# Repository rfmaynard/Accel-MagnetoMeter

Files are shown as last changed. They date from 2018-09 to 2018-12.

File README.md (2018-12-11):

Accel/Magnetometer project build instructions
=============================================

Table of Contents
-----------------

1.  [Introduction](https://github.com/rfmaynard/Accel-MagnetoMeter#introduction)

2.  [Bill of
    Materials/Budget](https://github.com/rfmaynard/Accel-MagnetoMeter#bill-of-materialsbudget)

3.  [Time](https://github.com/rfmaynard/Accel-MagnetoMeter#time)

4.  [Assembly](https://github.com/rfmaynard/Accel-MagnetoMeter#assembly)

5.  [PCB/Soldering](https://github.com/rfmaynard/Accel-MagnetoMeter#pcbsoldering)

6.  [Power Up](https://github.com/rfmaynard/Accel-MagnetoMeter#power-up)

7.  [Unit Testing](https://github.com/rfmaynard/Accel-MagnetoMeter#unit-testing)

8.  [Production
    Testing](/github.com/rfmaynard/Accel-MagnetoMeter#production-testing)

### Introduction

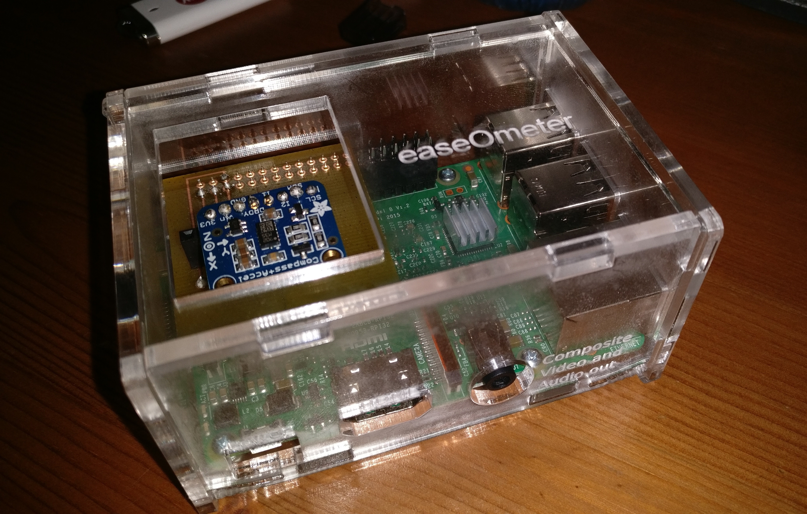
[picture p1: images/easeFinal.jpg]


Hello and welcome to the (unofficial) build instructions and guide to using the
LSM303 Accelerometer and Magnetometer. The scope of this little project is to
learn and integrate a piece of hardware and broadcomm development platform
together. In our case, we will be using a Raspberry Pi B as our platform. All of
which can then be used for real world applications. A potential case for this
project, imaged below, which my group and I will be attempting in the next
semester, will be a simple pedometer.

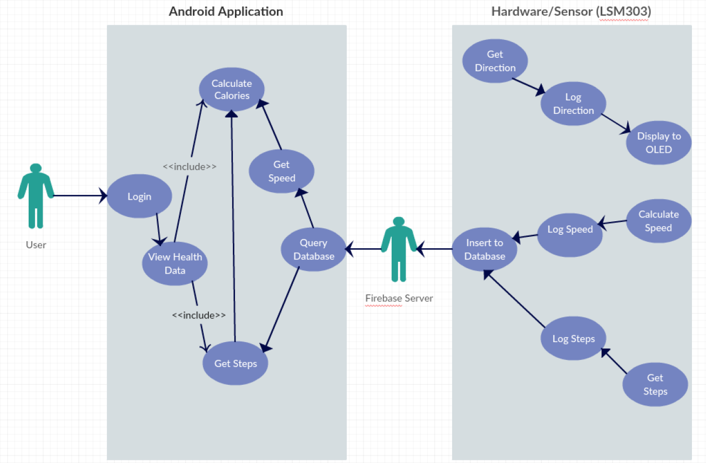
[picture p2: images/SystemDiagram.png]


Now let’s get into it!

### Bill of Materials/Budget

Budget with part links
[HERE](https://github.com/rfmaynard/Accel-MagnetoMeter/blob/master/documentation/BeginnerBudget.xlsx)

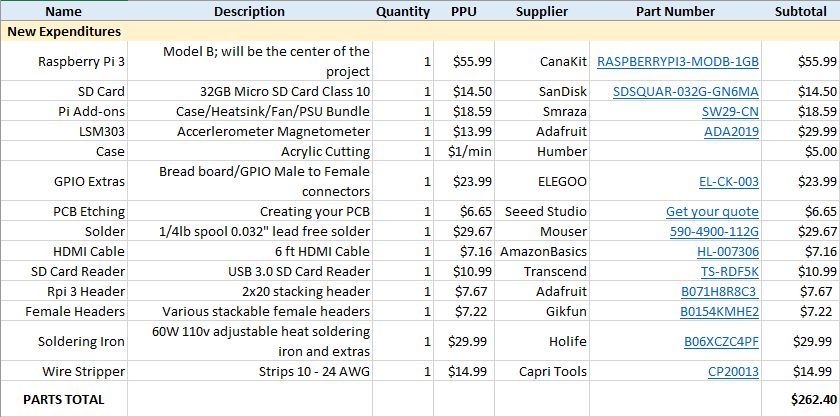
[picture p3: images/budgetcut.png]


Firstly, you will need to acquire certain parts in order to complete this
project. Shown above is the price break down for each component used. You may
not need all of them listed items, but it is everything I was required to use to
get the project to completion. Feel free to download the spreadsheet version of
the budget, as part links are provided.

### Time

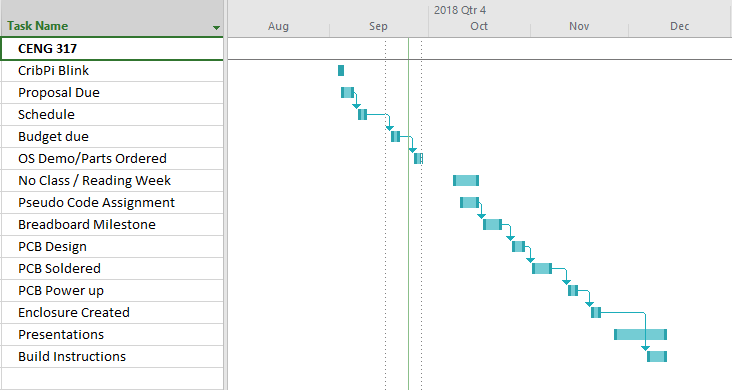
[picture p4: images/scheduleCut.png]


This project ran its course over an entire school semester (4 months, \~15
weeks), and the amount of time spent on it per week, on average, I’d say was
about 1 to 2 hours. Assuming that those reading this are at the average skill
level in using a computer and hardware, a user would be able to complete this
potentially over a weekend. The one time constraint that isn’t always certain is
how long the parts will take to arrive. When ordering your parts, ensure that
the seller/supplier provides appropriate delivery time estimates. This will
ensure smooth assembly of your project!

### Assembly

**Step 1: Preparing your Raspberry Pi**

In this step we will cover basic Raspberry Pi imaging so you are able to login
and access your device to test and drive your sensor later on!

1.  Download the latest [Raspberry Pi
    image](https://www.raspberrypi.org/downloads/). My recommendation is NOOBS.
    This will ensure that starting off, you will have almost everything you need
    if you decide to re-purpose the device later on.

2.  Download [etcher](https://www.balena.io/etcher/). This program will allow
    you to burn the Raspberry Pi image to your SD card.

3.  Insert your SD card into the SD card reader and plug it into your computer.

4.  Open etcher and follow the on screen instructions to burn your image. I
    found this program the easiest to use. [Extra documentation if
    needed](https://www.raspberrypi.org/documentation/installation/installing-images/README.md).

5.  Insert the SD card into your Raspberry Pi along the underside of the device,
    logo facing out. Plug all of the required cables in such as: Ethernet, HDMI
    cable, mouse, keyboard, power, and turn the device on.

6.  Upon boot you will see an option for different operating systems. Select
    **Raspbian** and follow the on screen instructions to complete the OS
    install. If you want, grab a coffee or snack as the install may take some
    time.

7.  At this point the Pi should boot to desktop. Follow the additional set up
    options on screen.

8.  Enable I2C. This is the method we will be using to communicated with our
    Raspberry Pi. Type `sudo apt-get install -y python-smbus i2c-tools` into the
    terminal by pressing `ctrl+alt+t`.

9.  Type `sudo raspi-config` into the terminal.

10. Go to interfacing options \> and enable I2C.

11. Power down with `sudo powerdown` from the terminal by pressing and set the
    Pi aside. We will not be using it until sensor testing.

**Step 2: Breadboarding and prototyping**

Here I will cover basic sensor connectivity to the Raspberry Pi by using a
breadboard for creating a mock layout/design that will be used in the PCB
creation stage.

1.  Gather the following items: Breadboard, LSM303 Sensor, and 4 Female-to-Male
    GPIO cables.

2.  Identify the labels on the sensor. For basic usage, we will be using: 3.3v,
    GND, SDA, and SCL.

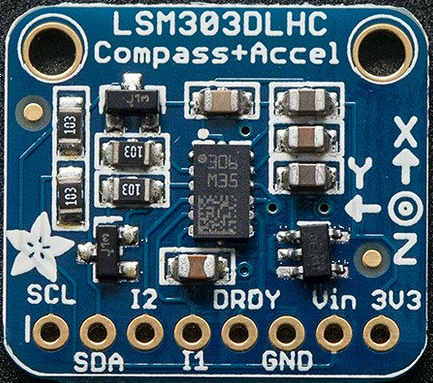
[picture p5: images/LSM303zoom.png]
    

3.  Identify the corresponding pinouts on the Raspberry Pi. [This website is a
    great tool to use if your are unsure.](https://pinout.xyz/#)

4.  Plug in the female part of the GPIO cables into the Raspberry Pi’s 1,3,5,
    and 6 pins, based on the chart from pinout.xyz. These are the pins we are
    going to be using for this project.

5.  Using the 8-pin connector that came with the LSM303 sensor, plug it into the
    breadboard and rest the LSM303 onto it as a placeholder.

6.  Connect the corresponding cables from the Raspberry Pi into the matched
    holes for the sensor.

7.  Voila! You have your mock up sensor connection!

It should look something like this:

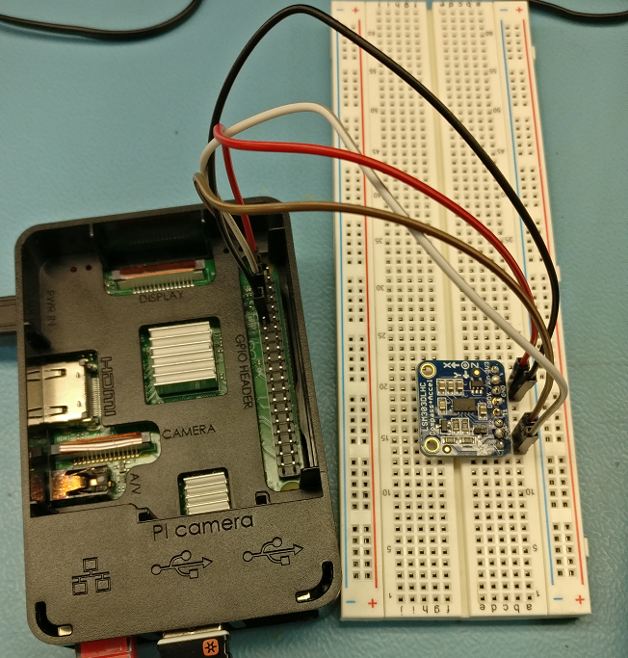
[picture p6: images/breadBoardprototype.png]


Now we can proceed to the PCB and soldering!

### PCB/Soldering

This is the part of the project that needs to be proceeded with care and
caution. I have made mistakes with my PCB design and case, however, I am
fortunate enough to have the resources at Humber to create 2nd or 3rd revisions
within a day or two. For those without access to such resources, it is advised
to double check your designs before purchasing etching and cutting services.

**Step 1: Fritzing**

[Fritzing](http://fritzing.org/download/) is an open-source application that
easily allows the user to create PCB schematics for different development
platforms. It is highly customizable and easy to use.

1.  [Download](http://fritzing.org/download/) and extract Fritzing. Installation
    notes are on the linked page for various operating systems.

2.  (Optional) Download the [AdaFruit Fritzing
    Library.](https://github.com/adafruit/Fritzing-Library) Handy if you want to
    take the extra step and create a mock or your own connection/designs in
    Fritzing.

3.  Download my Fritzing file
    [here](https://github.com/rfmaynard/Accel-MagnetoMeter/blob/master/pcb%20files/LSM303pi2.fzz)
    and open it. From the PCB tab, you can make changes at your leisure and pick
    it apart to see how it was made.

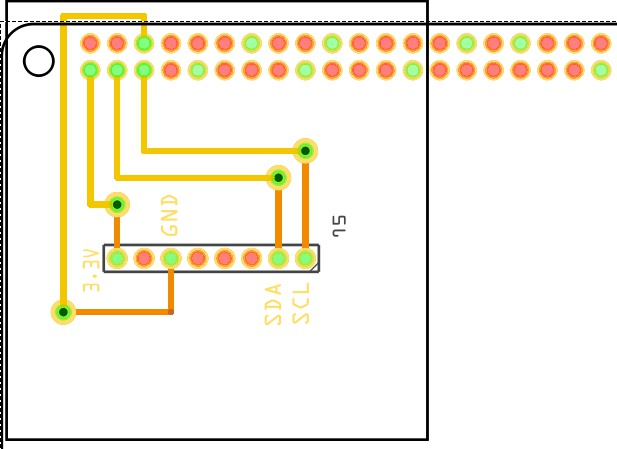
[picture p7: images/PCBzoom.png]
    

4.  Export as gerber. `File > Export for Production > Extended Gerber` and
    select an appropriate folder. These files will be required to create and
    etch your PCB.

5.  Zip/Compress the folder containing your gerber files and send them to your
    etcher of choice.

**Step 2: Soldering**

Once you have your PCB we are ready to solder our parts. **Note:** if you made
your own Fritzing design, please double check that it has the correct
connections.

1.  Gather your LSM303 sensor, copper wire, wire stripper, the 8-pin that came
    with the sensor, your PCB, solder, and soldering iron.

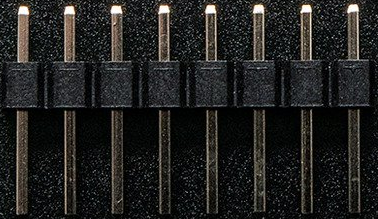
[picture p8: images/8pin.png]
    

2.  Solder your 8-pin that came with your sensor, pictured above, to your
    LSM303. Put the longer end of the 8-pin into your breadboard and place your
    sensor holes into the upright pins and solder all of the pins. This will
    ensure your sensor doesn’t move too much during soldering and a sturdy
    connection. **Note:** [Watch this video on soldering
    tips.](https://www.youtube.com/watch?v=oqV2xU1fee8) **Solder in a well
    ventilated area and use safety glasses.**

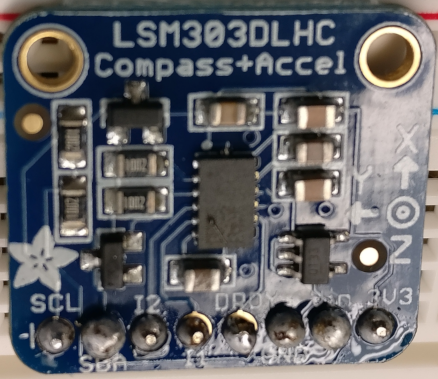
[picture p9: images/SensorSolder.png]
    

3.  (Optional) At this point you can test your sensor by applying it to the
    breadboard mockup from the previous section. Turn on your Pi with the sensor
    connected and run `i2cdetect -y 1` in the terminal. If working, should
    display the addresses `19` and `1e`.

4.  Solder your vias on your PCB. The easiest method I found, was to strip your
    copper wiring, stick it into the breadboard, and slide one via onto it so
    that it is flat and stable for soldering. Imaged below, and repeat for each
    via. Once each via is soldered, snip the excess wire with your cutters.

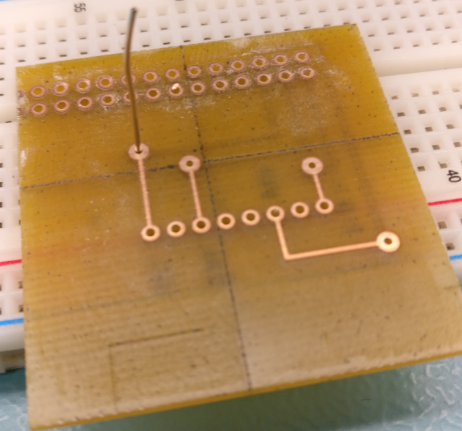
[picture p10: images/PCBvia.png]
    

5.  Solder your stackable headers. Using the breadboard again, take some extra
    copper wire from the snipped vias, or strip more, and place it into the
    female part of the header. The more, the sturdier. Flip the header over and
    plug it into the breadboard. Place your PCB onto the pins sticking out and
    solder the connections. Example below.

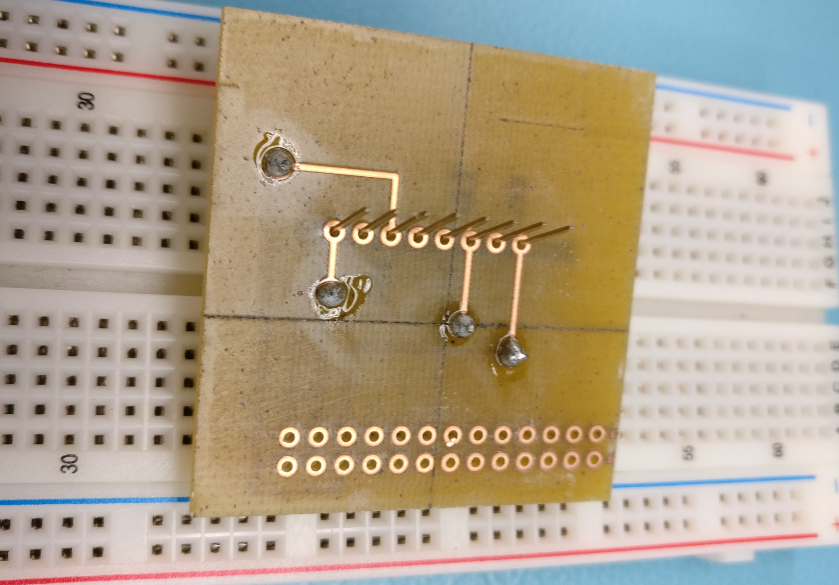
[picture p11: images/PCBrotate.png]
    

6.  Repeat the process for the 2x20 header for the Raspberry Pi. It’s not
    entirely necessary to solder all of the vias, but it ensures the PCB does
    not move as much.

7.  Your soldering should be complete. Plug everything in accordingly (i.e line
    up sensor to the correct vias and Pi header is soldered on 1,3,5 and 6), and
    you should be ready for the next step! Example below.

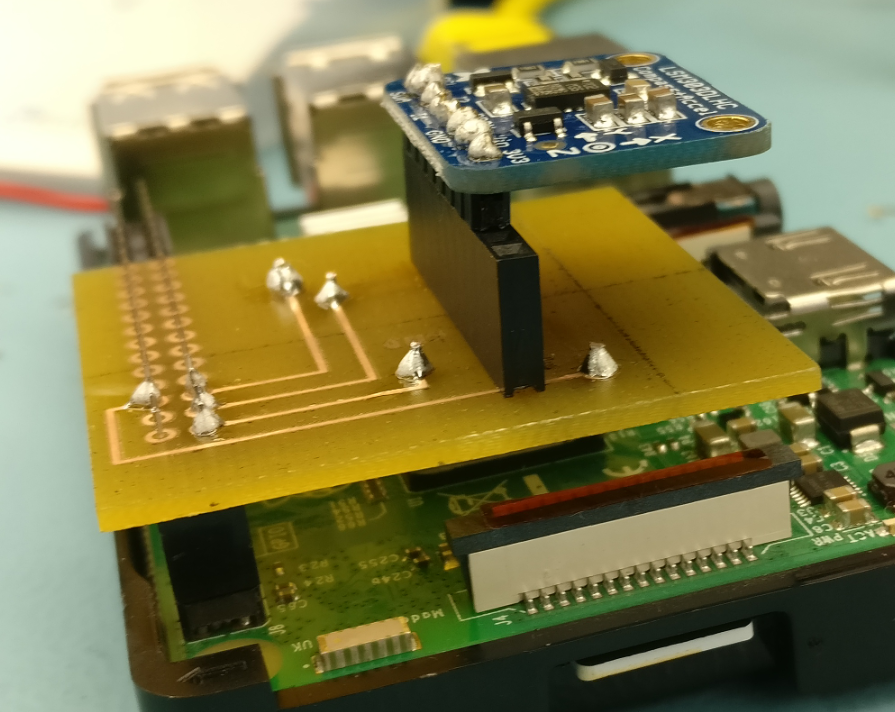
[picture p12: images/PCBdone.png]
    

### Power Up

Once everything is plugged in, and you have double checked your connections,
power on your Raspberry Pi.

1.  Open up the terminal once you are at the desktop, and run the command
    `i2cdetect -y 1`.

2.  Hopefully everything is in working order. If so, you will see this screen:

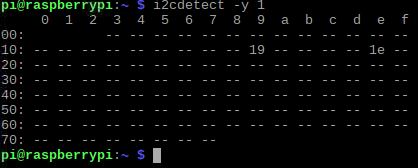
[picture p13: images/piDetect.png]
    

Congratulations! You can now move onto Unit Testing.

### Unit Testing

For this portion, you will need an internet connection as you will be required
to download libraries in order to get readings from the LSM303 sensor.

1.  Make sure your Pi is up to date with the latest packages. Run `sudo apt
    update` in the terminal to make sure everything is up to date.

2.  We will be using Python to test the LSM303 sensor, and will need the
    appropriate tools. Run the following commands in the terminal to ensure we
    have everything required to read from the sensor.

~~~~~~~~~~~~~~~~~~~~~~~~~~~~~~~~~~~~~~~~~~~~~~~~~~~~~~~~~~~~~~~~~~~~~~~~~~~~~~~~
sudo apt-get install git build-essential python-dev
cd ~
git clone https://github.com/adafruit/Adafruit_Python_LSM303.git
cd Adafruit_Python_LSM303
sudo python setup.py install
~~~~~~~~~~~~~~~~~~~~~~~~~~~~~~~~~~~~~~~~~~~~~~~~~~~~~~~~~~~~~~~~~~~~~~~~~~~~~~~~

3.  Navigate to the `/Adafruit_Python_LSM303/examples` directory.

4.  Test your sensor by running `python simpletest.py`. Your readings should
    look like this:

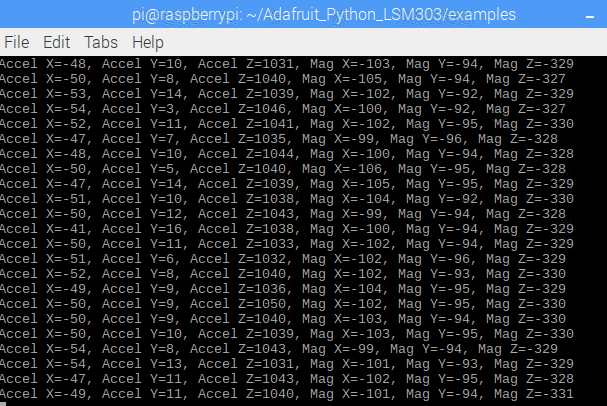
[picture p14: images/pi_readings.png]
    

5.  You can test the readings by moving your device in different directions with
    different speeds. You will notice the values changing accordingly.

Congratulations! Your sensor successfully works with your etched PCB and
Raspberry Pi. You can move onto Production Testing.

### Production Testing

[I have provided a case
file](https://github.com/rfmaynard/Accel-MagnetoMeter/blob/master/case%20files/easeOmeter_CaseFiles_v4.cdr)
(Created with CorelDraw x6) for those that wish to continue further for
potential real world use. This case will ensure your sensor, Pi, and PCB are
protected all while providing enough room for you to remove the sensor at your
leisure. For portability, there is definite room that can be improved upon if
you wish to make the device smaller and more portable. For my purposes, this
project was meant to be a robust and simple type pedometer prototype for the
aging population. I have taken it to and from school inside of my backpack for a
solid hour at a time and everything still works with no issues. This concludes
the end of the build instructions, I hope you had fun with this project as much
as I did!

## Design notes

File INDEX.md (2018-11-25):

easeOmeter project
==================

November 20th, 2018
-------------------

### Enclosure update:

Working with CorelDraw x6, we were provided a default file to work with. My
current edited version is just tall enough for the user to reach down and remove
the sensor, while still providing protection during transport.



As I write this, the prototype lab is in the process of cutting the acrylic
case. Below is the result of the case. However, it is apparent that the case is
still slightly flawed. I will need to make the top square for removing and
adding sensors slightly larger, and the PCB is just marginally too large. In
addition, I will need to procure standoffs for the Pi so it can stay elevated
inside the case. I was thinking of making those out of the acrylic from the
cuts. I will post an edited and updated case file as I continue to make
measurements and work on it.



Currently, the project remains on track and I double checked the sensor and Pi’s
functionality and everything is in working order. Financial status is unchanged
as I was able to acquire a custom case through the school thanks to the
prototype lab.

### Adjustments:



The above image details the above changes I mentioned. The indent in the side
panel will ensure my PCB will fit, and the enlarged square makes it easier to
get access to the sensor. Below is an image of the PCB slot, and the finished
product. The final files for the case can be found
[here](https://github.com/rfmaynard/Accel-MagnetoMeter/blob/master/case%20files/easeOmeter_CaseFiles_v4.cdr).





November 13th, 2018
-------------------

### PCB Update and hardware demonstration:



Successful, and corrected PCB soldered, and tested! Correctly detects the proper
address.



Moving on to the python libraries to being reading values, I noticed that trying
to connect to the school’s Wi-Fi network was greyed out in the GUI. Upon further
research I discovered that connecting to enterprise networks is disabled by
default. A work around to this was to enter information manually into the
/etc/wpa_supplicant/wpa_supplicant.conf file as shown below.



After installing python and the libraries for the sensor, the example code to
get readings works!



November 6th, 2018
------------------

### PCB soldering milestone update:



Unsuccessfully detects, and I am aware of the problem, and the solution.



### Progress Report:

The current schedule as of today is slightly behind. I unfortunately had a set
back where I got ahead of myself and failed to double check my sensor and
corresponding fritzing file. As a result, there was an error where my SDA was
located in the wrong spot along where the 8-pin header sits. I will need to get
my PCB remade for my mistake. This will set me back a few days but I will be
able to make up time by coming to school on my day off and working in the
prototype lab. Below is an image of the fixed error, and appropriate files are
located
[here](https://github.com/rfmaynard/Accel-MagnetoMeter/tree/master/pcb%20files).



I had everything soldered in the lab, and upon realizing my error, needed to
de-solder (a very handy tool by the way). Unfortunately, I had not documented
any pictures of the completed soldering. On the bright side, I was able to
procure an 8 and full GPIO headers from the prototype lab without any extra
costs. Financial status is still on track and has not changed. Overall, a minor
set back, but having already had the experience to solder it all, test, and
de-solder. Performing it the second time around should be a little faster and
feel more comfortable. Will be on track for next week (Week 11).

October 30th, 2018
------------------

### Fritzing and PCB Update:



### Progress Report:

The schedule of the EaseOmeter is proceeding as expected, and as stated before,
I am fortunate to be not hitting any major road blocks as of yet. The fritzing
was completed on time with the help of my professor’s clarification on some
designing techniques. It was suggested to prevent any lines from crossing as
that would interfere with the PCB etching, as well as instructing us on the
proper use of via’s and differentiating the differences between the top and
bottom of the PCB. I should be able to hit the Week 10 milestone next week.

Financial status is still OK as of right now and I am currently refining and
double checking the PCB part on fritzing before send off to the lab for etching.
Ground needs to be sent around the pins still as it would conflict with the GPIO
pins in the Raspberry Pi.

October 23rd, 2018
------------------

### Build Update:



Successfully Detects!



### Progress Report:

While on track for the most part, I fell behind in week 7 slightly as most
students had their sensors soldered. I made up the gap by mock bread-boarding my
sensor and Pi over the weekend leading toward week 8. One of the problems I
encountered was finding the correct GPIO labeling for this sensor as it is not
one of the more popular devices. Another neat solution to connecting to my Pi is
via a direct ethernet cable to my laptop along with VNC. This provides a simple
and quick connection.

As for any other extra amenities required, I needed an ethernet cable to connect
the Pi directly to my laptop, which happened to be lying around. Fritzing is
almost completed for the PCB etching in week 9. In all, this project is on track
and luckily, no major road bumps have occurred as of yet.

October 2nd, 2018
-----------------

### Proof of Purchase:







September 25th, 2018
--------------------

Budget Posted. Can be found
[here.](https://github.com/rfmaynard/Accel-MagnetoMeter/blob/master/documentation/EaseOMeter_Budget.pdf)

September 18th, 2018
--------------------

Schedule Posted. Can be found
[here.](https://github.com/rfmaynard/Accel-MagnetoMeter/blob/master/documentation/EaseOMeter_Schedule.PNG)

September 11th, 2018
--------------------

Proposal Posted. Can be found
[here.](https://github.com/rfmaynard/Accel-MagnetoMeter/blob/master/documentation/RyanMaynard_EaseOMeter_Proposal.pdf)

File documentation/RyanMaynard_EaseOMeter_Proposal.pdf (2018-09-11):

Submission Date | 2018-09-11
Project Name | Easeometer
Student Name | Ryan Maynard
Project repository | https://github.com/rfmaynard/Accel-MagnetoMeter
SensorEffector Choice | LSM303 Accelerometer & Magnetometer
The database will store | Speed, Velocity, Direction(Compass)
The mobile device functionality will include | View distance traveled for the day, calories burned, steps, toggle start/stop/pause/bike mode/walk mode
I will be collaborating with the following company/department | Humber School of Applied Technology
My group in the winter semester will include | Delroy Christie, Jonas Gamao
50 word problem statement | Simplfying the current pedometer for the aging generation looking to get healthy. Most older users are turned off by complex devices and UIs. Being able to monitor their own health by implementing a simple and user-friendly interface can lead to a more active lifestyle.
100 words of background | Pedometers/wearable/portable technology is used everywhere. With the baby boomers becoming an aging population, and with health concerns on the rise, this easy to use system can promote a healthier lifestyle with the added ease of use. By using IoT/Cloud software, users can track their usage and compare it over days/weeks/months to ensure they are getting the exercise needed.
Current product APA citation | KNOW YOURSELF TO IMPROVE YOURSELF. (n.d.). Retrieved from https://www.fitbit.com/en-ca/home
Existing research IEEE paper APA citation | Genovese, V., Mannini, A., & Sabatini, A. M. (2017). A Smartwatch Step Counter for Slow and Intermittent Ambulation. IEEE Access, 5, 13028-13037. doi:10.1109/access.2017.2702066
Brief description of planned purchases | Pi3, LSM303, GPIO Connectors, Case
Solution description | A user friendly, Cloud/IoT based pedometer for the technologically weak aging population.

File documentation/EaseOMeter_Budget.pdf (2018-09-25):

Name New Expenditures | Description | Quantity | PPU | Supplier | Part Number | Subtotal
SD Card | 32GB Micro SD Card Class 10 | 1 | $14.50 | SanDisk | SDSQUAR-032G-GN6MA (https://www.amazon.ca/Sandisk-SDSQUAR-032G-GN6MA-Ultra-Micro-Adapter/dp/B073JWXGNT?s=electronics) | $14.50
Pi Add-ons | Case/Heatsink/Fan/PSU Bundle | 1 | $18.59 | Smraza | SW29-CN (https://www.amazon.ca/Smraza-Wood-Case-Raspberry-Included/dp/B078GL2S5T?s=electronics) | $18.59
LSM303 | Accerlerometer Magnetometer | 1 | $13.99 | Adafruit | ADA2019 (https://www.amazon.ca/Adafruit-Triple-axis-Accelerometer-Magnetometer-Compass/dp/B0149KK6SW?s=aps) | $29.99
Case | Acrylic Cutting | 1 | $1/min | Humber
GPIO Expansion | GPIO Expansion board/GPIO Male to Female connectors | 1 | $15.99 | Quimat | QY18 (https://www.amazon.ca/Quimat-Expansion-Raspberry-Breadboard-QY18/dp/B074P27K5S?s=aps) | $15.99

Owned Parts

HDMI Cable | 6 ft HDMI Cable | 1 | $7.16 | AmazonBasics | HL-007306 (https://www.amazon.ca/AmazonBasics-High-Speed-HDMI-Cable-1-Pack/dp/B014I8SSD0?s=electronics) | $7.16
SD Card Reader | USB 3.0 SD Card Reader | 1 | $10.99 | Transcend | TS-RDF5K (https://www.amazon.ca/Transcend-Information-Card-Reader-TS-RDF5K/dp/B009D79VH4?s=electronics) | $10.99
Raspberry Pi 3 | Model B; will be the center of the
project
1 | $55.99 | CanaKit | RASPBERRYPI3-MODB-1GB (https://www.amazon.ca/Raspberry-Pi-RASPBERRYPI3-MODB-1GB-Model-Motherboard/dp/B01CD5VC92) | $55.99
Parts Kit | Humber College Parts Kit | 1 | $109.99 | Humber College | $109.99
CURRENT PARTS TOTAL | $263.20
NEW PURCHASE TOTAL | $135.06
ALL PARTS TOTAL | $398.26
NEW PURCHASE TAXES | $152.62
NEW PURCHASE SHIPPING | $18.23

FINAL NEW
PURCHASE TOTAL

$170.85

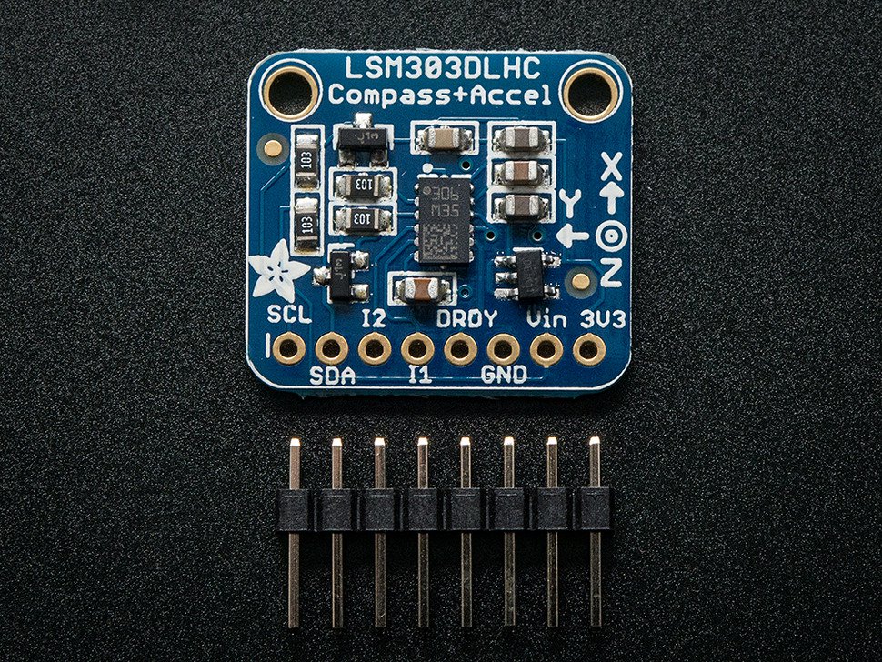
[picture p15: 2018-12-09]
images/LSM303-ada.jpg

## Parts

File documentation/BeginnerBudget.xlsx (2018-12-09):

Name | Description | Quantity | PPU | Supplier | Part Number | Subtotal
New Expenditures
Raspberry Pi 3 | Model B; will be the center of the project | 1 | $55.99 | CanaKit | RASPBERRYPI3-MODB-1GB (https://www.amazon.ca/Raspberry-Pi-RASPBERRYPI3-MODB-1GB-Model-Motherboard/dp/B01CD5VC92) | $55.99
SD Card | 32GB Micro SD Card Class 10 | 1 | $14.50 | SanDisk | SDSQUAR-032G-GN6MA (https://www.amazon.ca/Sandisk-SDSQUAR-032G-GN6MA-Ultra-Micro-Adapter/dp/B073JWXGNT?s=electronics) | $14.50
Pi Add-ons | Case/Heatsink/Fan/PSU Bundle | 1 | $18.59 | Smraza | SW29-CN (https://www.amazon.ca/Smraza-Wood-Case-Raspberry-Included/dp/B078GL2S5T?s=electronics) | $18.59
LSM303 | Accerlerometer Magnetometer | 1 | $13.99 | Adafruit | ADA2019 (https://www.amazon.ca/Adafruit-Triple-axis-Accelerometer-Magnetometer-Compass/dp/B0149KK6SW?s=aps) | $29.99
Case | Acrylic Cutting | 1 | $1/min | Humber |  | $5.00
GPIO Extras | Bread board/GPIO Male to Female connectors | 1 | $23.99 | ELEGOO | EL-CK-003 (https://www.amazon.ca/gp/product/B01ERPEMAC/ref=oh_aui_detailpage_o01_s00?ie=UTF8&psc=1) | $23.99
PCB Etching | Creating your PCB | 1 | $6.65 | Seeed Studio | Get your quote (https://www.seeedstudio.com/fusion_pcb.html) | $6.65
Solder | 1/4lb spool 0.032" lead free solder | 1 | $29.67 | Mouser | 590-4900-112G (https://www.mouser.ca/ProductDetail/MG-Chemicals/4900-112G?qs=YqNA2qefETAK87e3A6%2fOig%3d%3d) | $29.67
HDMI Cable | 6 ft HDMI Cable | 1 | $7.16 | AmazonBasics | HL-007306 (https://www.amazon.ca/AmazonBasics-High-Speed-HDMI-Cable-1-Pack/dp/B014I8SSD0?s=electronics) | $7.16
SD Card Reader | USB 3.0 SD Card Reader | 1 | $10.99 | Transcend | TS-RDF5K (https://www.amazon.ca/Transcend-Information-Card-Reader-TS-RDF5K/dp/B009D79VH4?s=electronics) | $10.99
Rpi 3 Header | 2x20 stacking header | 1 | $7.67 | Adafruit | B071H8R8C3 (https://www.amazon.com/Adafruit-GPIO-Stacking-Header-ADA2223/dp/B071H8R8C3) | $7.67
Female Headers | Various stackable female headers | 1 | $7.22 | Gikfun | B0154KMHE2 (https://www.amazon.ca/Gikfun-2-54mm-Stackable-Female-Arduino/dp/B0154KMHE2) | $7.22
Soldering Iron | 60W 110v adjustable heat soldering iron and extras | 1 | $29.99 | Holife | B06XCZC4PF (https://www.amazon.ca/Holife-Adjustable-Temperature-Controlled-Interchangeable/dp/B06XCZC4PF) | $29.99
Wire Stripper | Strips 10 - 24 AWG | 1 | $14.99 | Capri Tools | CP20013 (https://www.amazon.ca/Capri-Tools-CP20013-Professional-Stripper/dp/B01018D07K?s=hi) | $14.99
PARTS TOTAL |  |  |  |  |  | $262.40

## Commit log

2018-11-06 changes updates
    [LSM303pi2.fzz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]
2018-11-20 case file updates
